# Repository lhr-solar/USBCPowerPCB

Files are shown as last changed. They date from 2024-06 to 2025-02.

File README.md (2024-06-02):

# USBCPowerPCB
Author: Ishan Deshpande

The purpose of this board is to be able to use a USB Type-C laptop charger to run one LV system (such as BPS or Controls). The dongle will act as a breakout; negotiating the power delivery at a fixed voltage with the laptop charger and delivering as much current as needed at a stable voltage of 12V/5V.

Currently under active development. Please reference the [USB-C PD Dongle Design Document](https://cloud.wikis.utexas.edu/wiki/spaces/LHRSOLAR/pages/28287742/2024+-+2026+USB-C+PD+Dongle+Design+Document) for more information.

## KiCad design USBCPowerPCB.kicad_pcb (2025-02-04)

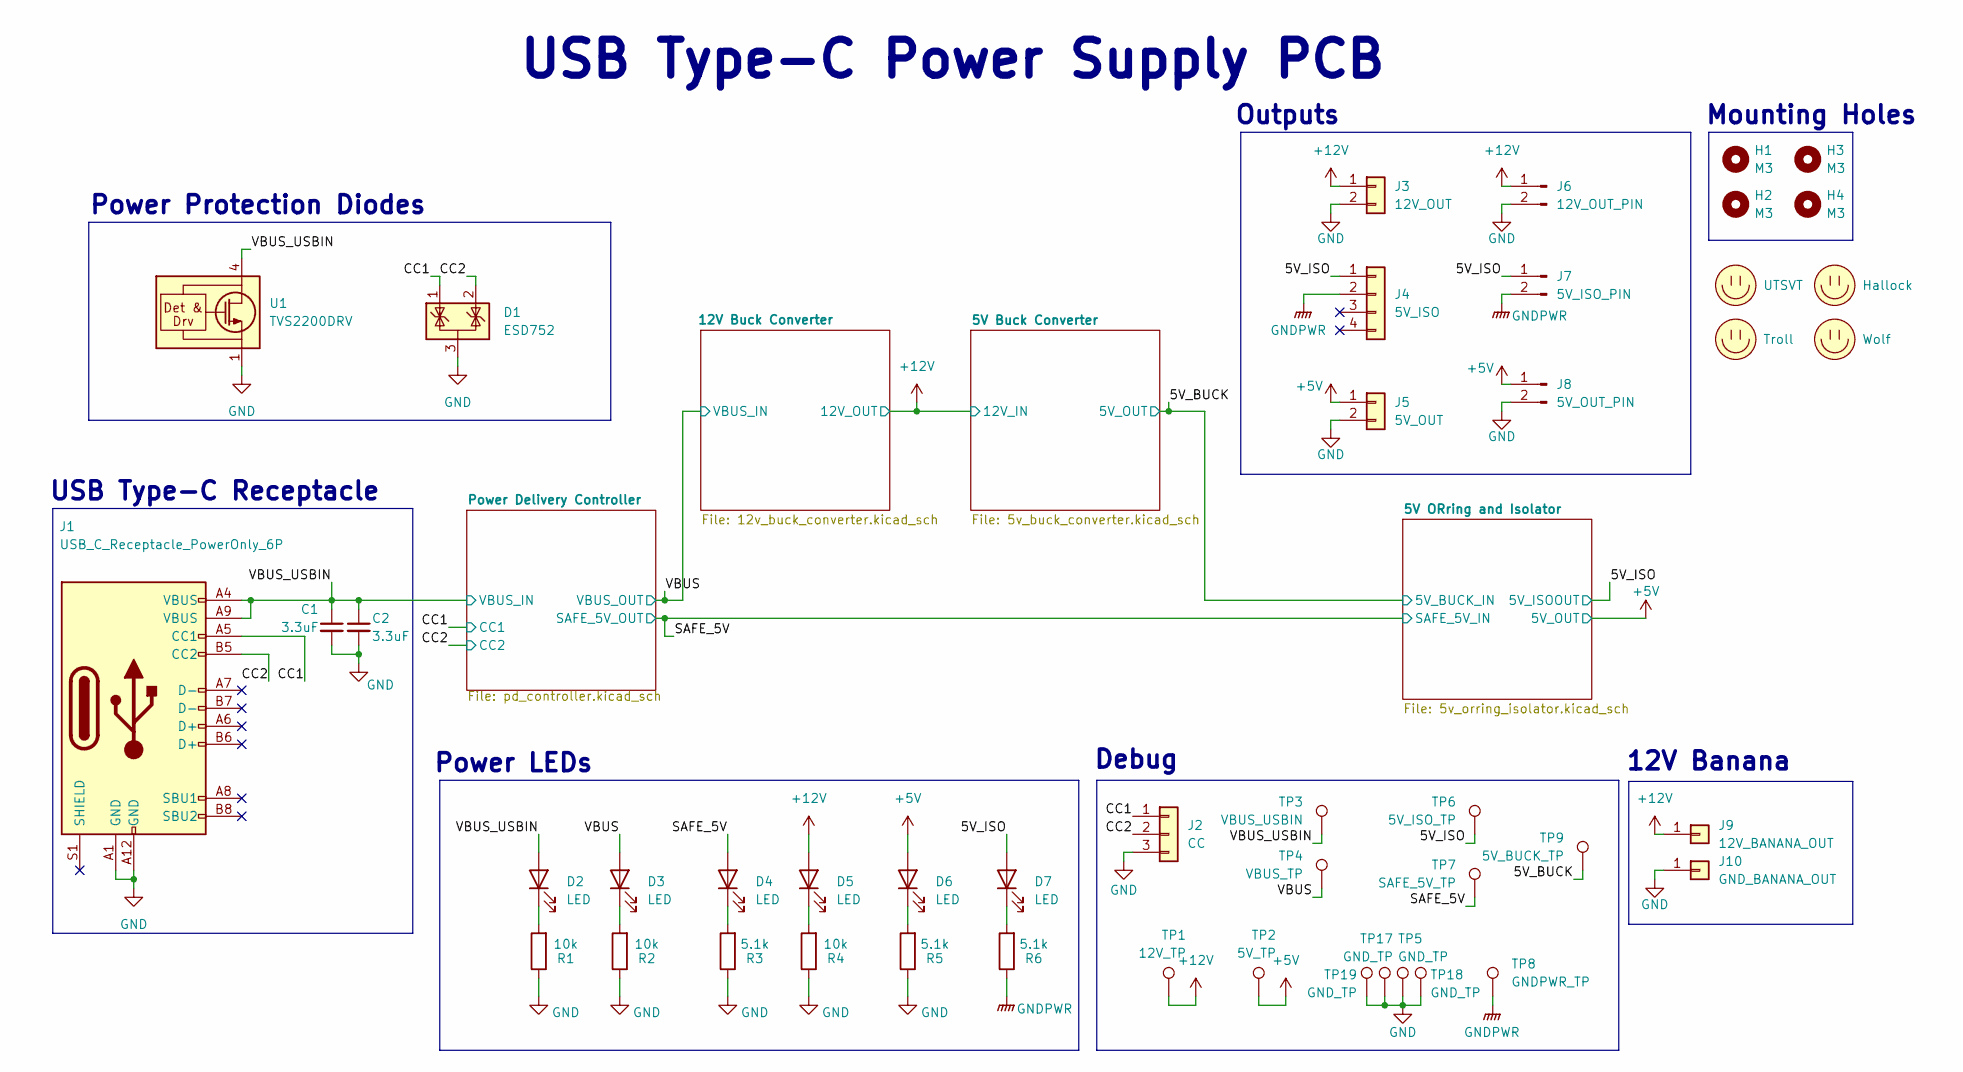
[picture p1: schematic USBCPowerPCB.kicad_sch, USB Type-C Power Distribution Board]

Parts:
C1, C2: 3.3uF; C_0805_2012Metric
D1: ESD752; SOT-23; Mouser Part Number ESD752DBZR
D2, D3, D4, D5, D6, D7: LED; LED_0805_2012Metric
H1, H2, H3, H4: M3; MountingHole_3.2mm_M3
J1: USB_C_Receptacle_PowerOnly_6P; CUI_UJ20-C-H-C-4-SMT-TR
J2: CC; PinHeader_1x03_P2.54mm_Vertical
J3: 12V_OUT; Molex_MicroFit3.0_1x2xP3.00mm_PolarizingPeg_Vertical
J4: 5V_ISO; Molex_MicroFit3.0_1x4xP3.00mm_PolarizingPeg_Vertical
J5: 5V_OUT; Molex_MicroFit3.0_1x2xP3.00mm_PolarizingPeg_Vertical
J6: 12V_OUT_PIN; PinHeader_1x02_P2.54mm_Vertical
J7: 5V_ISO_PIN; PinHeader_1x02_P2.54mm_Vertical
J8: 5V_OUT_PIN; PinHeader_1x02_P2.54mm_Vertical
J9: 12V_BANANA_OUT; Banana_Jack_Horizontal
J10: GND_BANANA_OUT; Banana_Jack_Horizontal
LOGO1: UTSVT; UTSVT_Logo_Symbol
LOGO2: Hallock; Hallock_Image_Tiny
LOGO3: Troll; troll
LOGO4: Wolf; wolf_front
R1, R2, R4: 10k; R_0805_2012Metric
R3, R5, R6: 5.1k; R_0805_2012Metric
TP1: 12V_TP; TestPoint_Plated_Hole_D2.0mm
TP2: 5V_TP; TestPoint_Plated_Hole_D2.0mm
TP3: VBUS_USBIN; TestPoint_Plated_Hole_D2.0mm
TP4: VBUS_TP; TestPoint_Plated_Hole_D2.0mm
TP5, TP17, TP18: GND_TP; TestPoint_THTPad_1.0x1.0mm_Drill0.5mm
TP6: 5V_ISO_TP; TestPoint_Plated_Hole_D2.0mm
TP7: SAFE_5V_TP; TestPoint_Plated_Hole_D2.0mm
TP8: GNDPWR_TP; TestPoint_Plated_Hole_D2.0mm
TP9: 5V_BUCK_TP; TestPoint_Plated_Hole_D2.0mm
TP19: GND_TP; TestPoint_Plated_Hole_D2.0mm
U1: TVS2200DRV; WSON-6-1EP_2x2mm_P0.65mm_EP1x1.6mm

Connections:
+5V: D6.2 (A), J5.1, J8.1, TP2.1; also elsewhere on the board
+12V: D5.2 (A), J3.1, J6.1, J9.1, TP1.1; also elsewhere on the board
/5V_BUCK: TP9.1; also elsewhere on the board
/5V_ISO: D7.2 (A), J4.1, J7.1, TP6.1; also elsewhere on the board
/CC1: D1.1 (K), J1.A5 (CC1), J2.1; also elsewhere on the board
/CC2: D1.2 (K), J1.B5 (CC2), J2.2; also elsewhere on the board
/SAFE_5V: D4.2 (A), TP7.1; also elsewhere on the board
/VBUS: D3.2 (A), TP4.1; also elsewhere on the board
/VBUS_USBIN: C1.1, C2.1, D2.2 (A), J1.A4 (VBUS), J1.A9 (VBUS), J1.B4 (VBUS), J1.B9 (VBUS), TP3.1, U1.4 (IN), U1.5 (IN), U1.6 (IN); also elsewhere on the board
GND: C1.2, C2.2, D1.3 (A), J1.A1 (GND), J1.A12 (GND), J1.B1 (GND), J1.B12 (GND), J2.3, J3.2, J5.2, J6.2, J8.2, J10.1, R1.1, R2.1, R3.1, R4.1, R5.1, TP5.1, TP17.1, TP18.1, TP19.1, U1.1 (GND), U1.2 (GND), U1.3 (GND), U1.7 (GND); also elsewhere on the board
GNDPWR: J4.2, J7.2, R6.1, TP8.1; also elsewhere on the board
unnamed: D2.1 (K), R1.2
unnamed: D3.1 (K), R2.2
unnamed: D4.1 (K), R3.2
unnamed: D5.1 (K), R4.2
unnamed: D6.1 (K), R5.2
unnamed: D7.1 (K), R6.2

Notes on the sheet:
Outputs
Mounting Holes
Debug
Power LEDs
USB Type-C Power Supply PCB
USB Type-C Receptacle
12V Banana
Power Protection Diodes

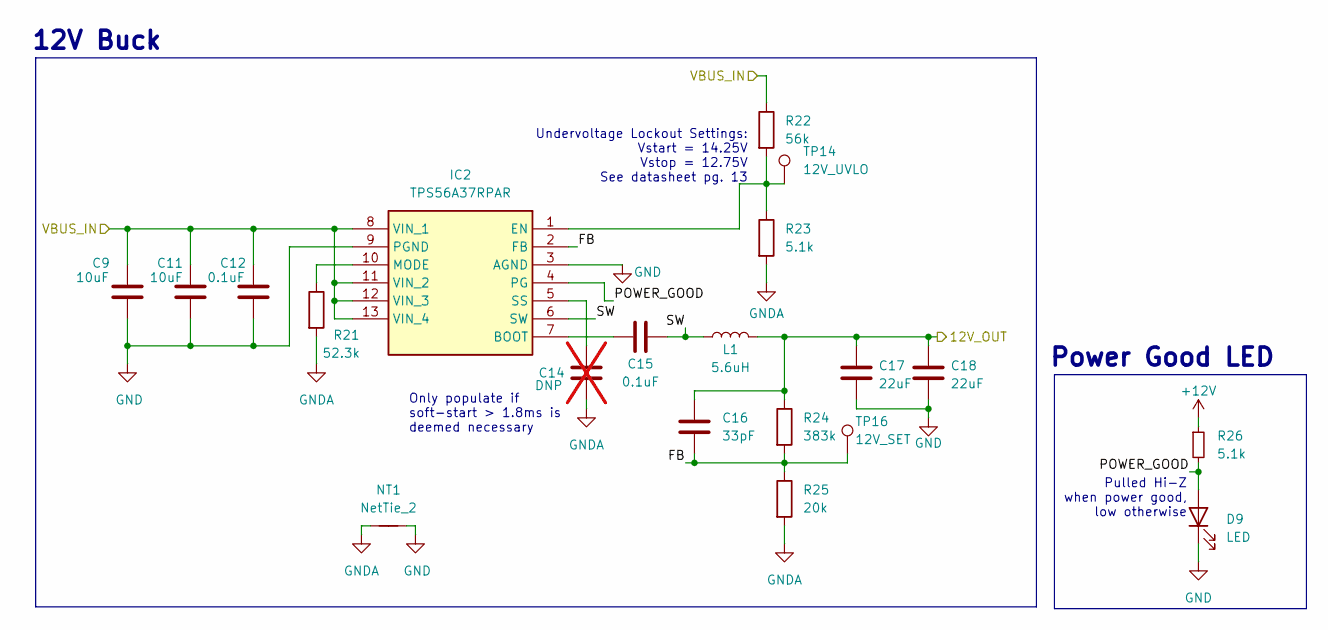
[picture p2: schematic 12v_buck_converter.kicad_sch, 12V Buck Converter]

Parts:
C9, C11: 10uF; C_0805_2012Metric
C12, C15: 0.1uF; C_0805_2012Metric
C14: DNP; C_0805_2012Metric; not fitted
C16: 33pF; C_0805_2012Metric
C17, C18: 22uF; C_0805_2012Metric
D9: LED; LED_0805_2012Metric
IC2: TPS56A37RPAR; Manufacturer_Part_Number TPS56A37RPAR
L1: 5.6uH; L_Bourns_SRP1038C_10.0x10.0mm
NT1: NetTie_2; NetTie-2_SMD_Pad2.0mm
R21: 52.3k; R_0805_2012Metric
R22: 56k; R_0805_2012Metric
R23, R26: 5.1k; R_0805_2012Metric
R24: 383k; R_0805_2012Metric
R25: 20k; R_0805_2012Metric
TP14: 12V_UVLO; TestPoint_THTPad_1.0x1.0mm_Drill0.5mm
TP16: 12V_SET; TestPoint_THTPad_1.0x1.0mm_Drill0.5mm

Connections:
+12V: C16.1, C17.1, C18.1, L1.2, R24.1, R26.1; also elsewhere on the board
/12V Buck Converter/FB: C16.2, IC2.2 (FB), R24.2, R25.1, TP16.1
/12V Buck Converter/POWER_GOOD: D9.2 (A), IC2.4 (PG), R26.2
/12V Buck Converter/SW: C15.2, IC2.6 (SW), L1.1
/VBUS: C9.1, C11.1, C12.1, IC2.8 (VIN_1), IC2.11 (VIN_2), IC2.12 (VIN_3), IC2.13 (VIN_4), R22.1; also elsewhere on the board
GND: C9.2, C11.2, C12.2, C17.2, C18.2, D9.1 (K), IC2.3 (AGND), IC2.9 (PGND), NT1.2; also elsewhere on the board
GNDA: C14.2, NT1.1, R21.2, R23.2, R25.2
unnamed: C15.1, IC2.7 (BOOT)
unnamed: IC2.1 (EN), R22.2, R23.1, TP14.1
unnamed: IC2.10 (MODE), R21.1
unnamed: C14.1, IC2.5 (SS)

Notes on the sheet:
Only populate if soft-start > 1.8ms is deemed necessary
Undervoltage Lockout Settings: Vstart = 14.25V Vstop = 12.75V See datasheet pg. 13
Pulled Hi-Z when power good, low otherwise
Power Good LED
12V Buck

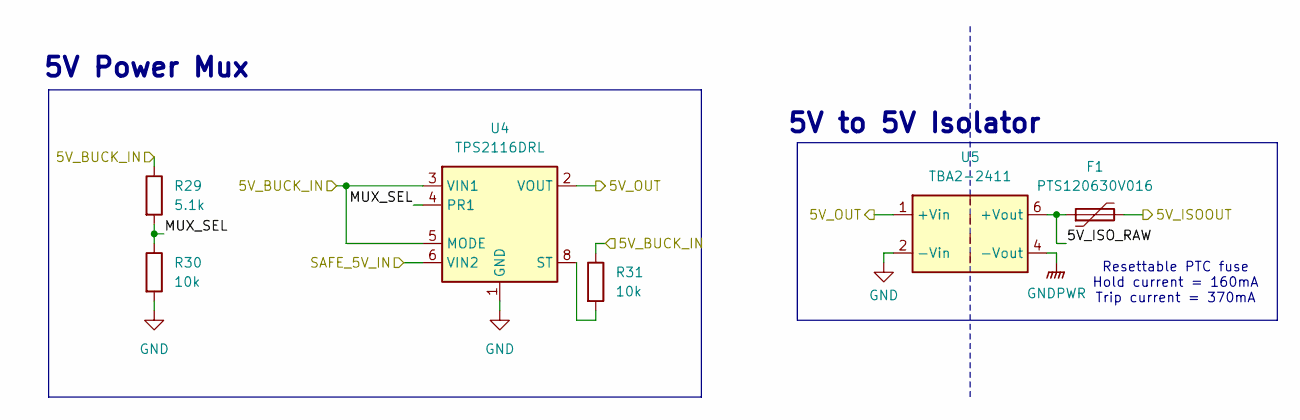
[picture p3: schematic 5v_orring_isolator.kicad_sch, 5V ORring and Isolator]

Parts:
F1: PTS120630V016; Fuse_1206_3216Metric
R29: 5.1k; R_0805_2012Metric
R30, R31: 10k; R_0805_2012Metric
U4: TPS2116DRL; SOT-583-8
U5: TBA2-2411; Converter_DCDC_TRACO_TBA2-xxxx_Single_THT

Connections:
+5V: U4.2 (VOUT), U4.7 (VOUT), U5.1 (+Vin); also elsewhere on the board
/5V ORring and Isolator/5V_ISO_RAW: F1.1, U5.6 (+Vout)
/5V ORring and Isolator/MUX_SEL: R29.2, R30.1, U4.4 (PR1)
/5V_BUCK: R29.1, R31.1, U4.3 (VIN1), U4.5 (MODE); also elsewhere on the board
/5V_ISO: F1.2; also elsewhere on the board
/SAFE_5V: U4.6 (VIN2); also elsewhere on the board
GND: R30.2, U4.1 (GND), U5.2 (-Vin); also elsewhere on the board
GNDPWR: U5.4 (-Vout); also elsewhere on the board
unnamed: R31.2, U4.8 (ST)

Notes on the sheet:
5V Power Mux
Resettable PTC fuse Hold current = 160mA Trip current = 370mA
5V to 5V Isolator

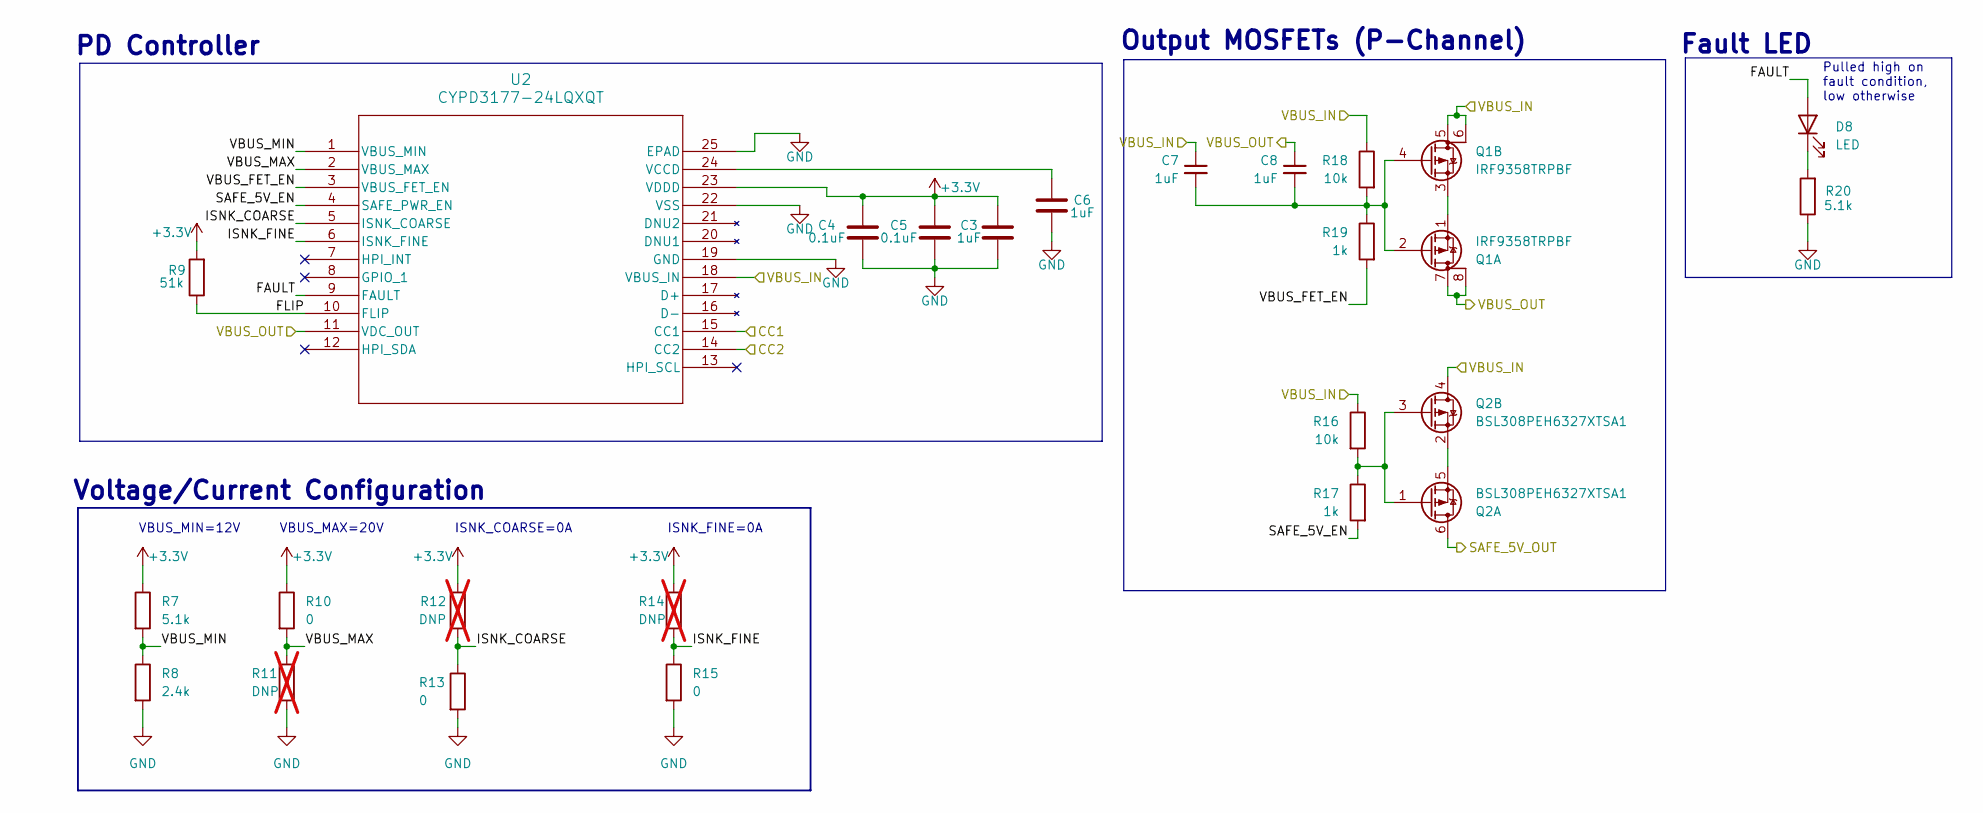
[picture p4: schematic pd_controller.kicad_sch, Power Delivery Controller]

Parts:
C3, C6, C7, C8: 1uF; C_0805_2012Metric
C4, C5: 0.1uF; C_0805_2012Metric
D8: LED; LED_0805_2012Metric
Q1: IRF9358TRPBF; SO-8_3.9x4.9mm_P1.27mm
Q2: BSL308PEH6327XTSA1; SOT-23-6
R7, R20: 5.1k; R_0805_2012Metric
R8: 2.4k; R_0805_2012Metric
R9: 51k; R_0805_2012Metric
R10, R13, R15: 0; R_0805_2012Metric
R11, R12, R14: DNP; R_0805_2012Metric; not fitted
R16, R18: 10k; R_0805_2012Metric
R17, R19: 1k; R_0805_2012Metric
U2: CYPD3177-24LQXQT; CYPD3177-24LQXQT_CYP

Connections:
+3.3V: C3.2, C4.2, C5.2, R7.1, R9.2, R10.1, R12.1, R14.1, U2.23 (VDDD)
/CC1: U2.15 (CC1); also elsewhere on the board
/CC2: U2.14 (CC2); also elsewhere on the board
/Power Delivery Controller/FAULT: D8.2 (A), U2.9 (FAULT)
/Power Delivery Controller/FLIP: R9.1, U2.10 (FLIP)
/Power Delivery Controller/ISNK_COARSE: R12.2, R13.1, U2.5 (ISNK_COARSE)
/Power Delivery Controller/ISNK_FINE: R14.2, R15.1, U2.6 (ISNK_FINE)
/Power Delivery Controller/SAFE_5V_EN: R17.2, U2.4 (SAFE_PWR_EN)
/Power Delivery Controller/VBUS_FET_EN: R19.2, U2.3 (VBUS_FET_EN)
/Power Delivery Controller/VBUS_MAX: R10.2, R11.1, U2.2 (VBUS_MAX)
/Power Delivery Controller/VBUS_MIN: R7.2, R8.1, U2.1 (VBUS_MIN)
/SAFE_5V: Q2.6 (D); also elsewhere on the board
/VBUS: C8.1, Q1.7 (D), Q1.8 (D), U2.11 (VDC_OUT); also elsewhere on the board
/VBUS_USBIN: C7.1, Q1.5 (D), Q1.6 (D), Q2.4 (D), R16.1, R18.1, U2.18 (VBUS_IN); also elsewhere on the board
GND: C3.1, C4.1, C5.1, C6.1, R8.2, R11.2, R13.2, R15.2, R20.1, U2.19 (GND), U2.22 (VSS), U2.25 (EPAD); also elsewhere on the board
unnamed: D8.1 (K), R20.2
unnamed: C7.2, C8.2, Q1.2 (G), Q1.4 (G), R18.2, R19.1
unnamed: Q1.1 (S), Q1.3 (S)
unnamed: Q2.1 (G), Q2.3 (G), R16.2, R17.1
unnamed: Q2.2 (S), Q2.5 (S)
unnamed: C6.2, U2.24 (VCCD)

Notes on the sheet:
VBUS_MAX=20V
Fault LED
Voltage/Current Configuration
Pulled high on fault condition, low otherwise
PD Controller
ISNK_COARSE=0A
Output MOSFETs (P-Channel)
ISNK_FINE=0A
VBUS_MIN=12V

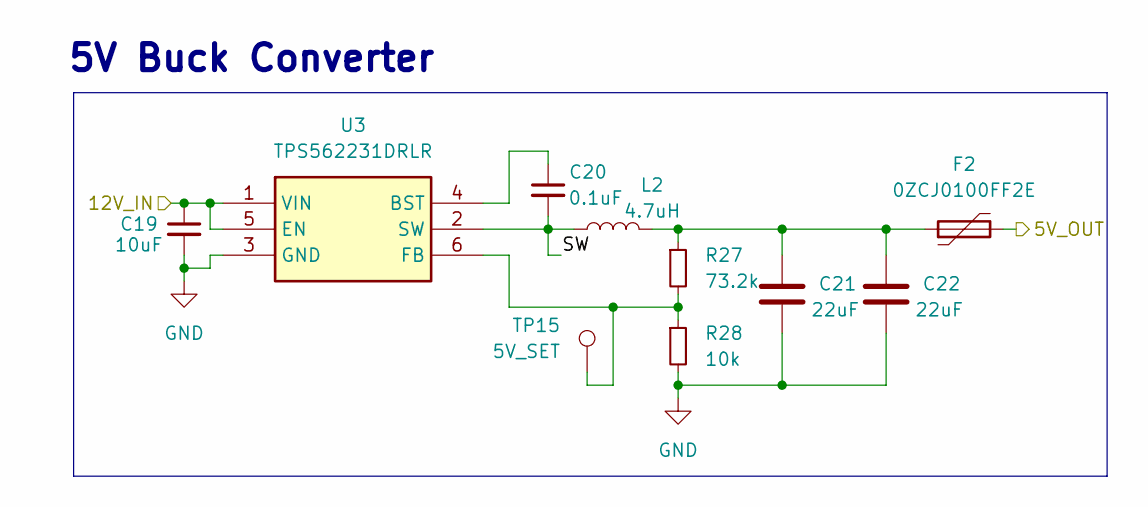
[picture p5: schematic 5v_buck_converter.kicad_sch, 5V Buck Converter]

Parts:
C19: 10uF; C_0805_2012Metric
C20: 0.1uF; C_0805_2012Metric
C21, C22: 22uF; C_0805_2012Metric
F2: 0ZCJ0100FF2E; Fuse_1206_3216Metric
L2: 4.7uH; INDPM5452X300N
R27: 73.2k; R_0805_2012Metric
R28: 10k; R_0805_2012Metric
TP15: 5V_SET; TestPoint_THTPad_1.0x1.0mm_Drill0.5mm
U3: TPS562231DRLR; SOT-563

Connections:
+12V: C19.1, U3.1 (VIN), U3.5 (EN); also elsewhere on the board
/5V Buck Converter/SW: C20.2, L2.1, U3.2 (SW)
/5V_BUCK: F2.2; also elsewhere on the board
GND: C19.2, C21.2, C22.2, R28.2, U3.3 (GND); also elsewhere on the board
unnamed: C21.1, C22.1, F2.1, L2.2, R27.1
unnamed: C20.1, U3.4 (BST)
unnamed: R27.2, R28.1, TP15.1, U3.6 (FB)

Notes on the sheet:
5V Buck Converter

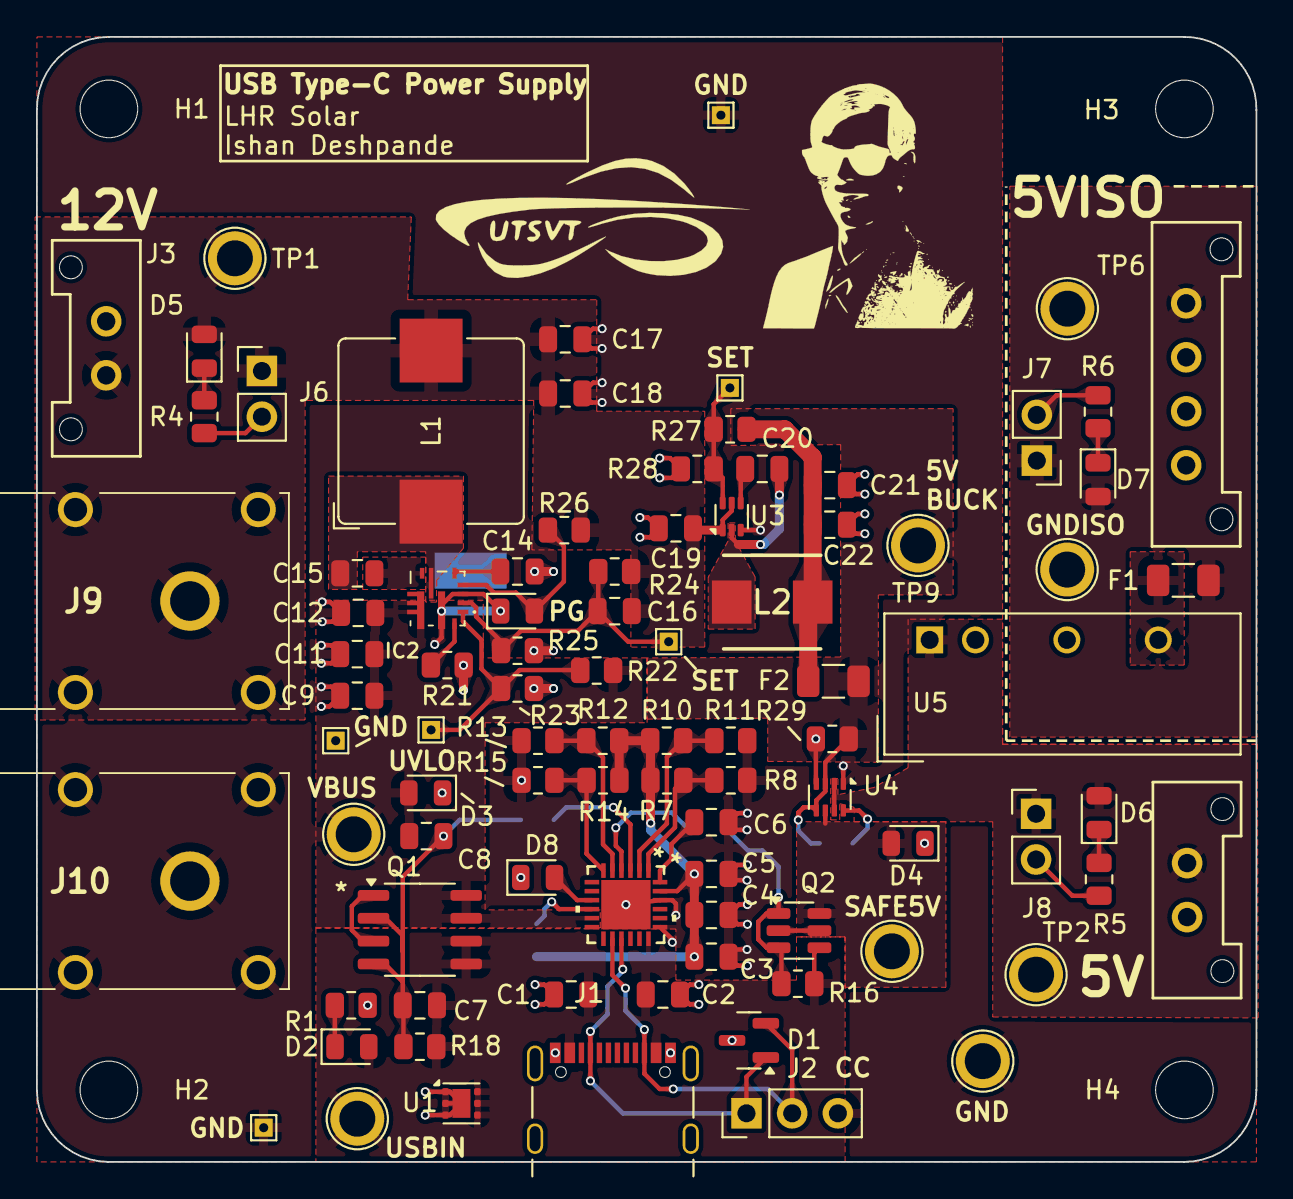
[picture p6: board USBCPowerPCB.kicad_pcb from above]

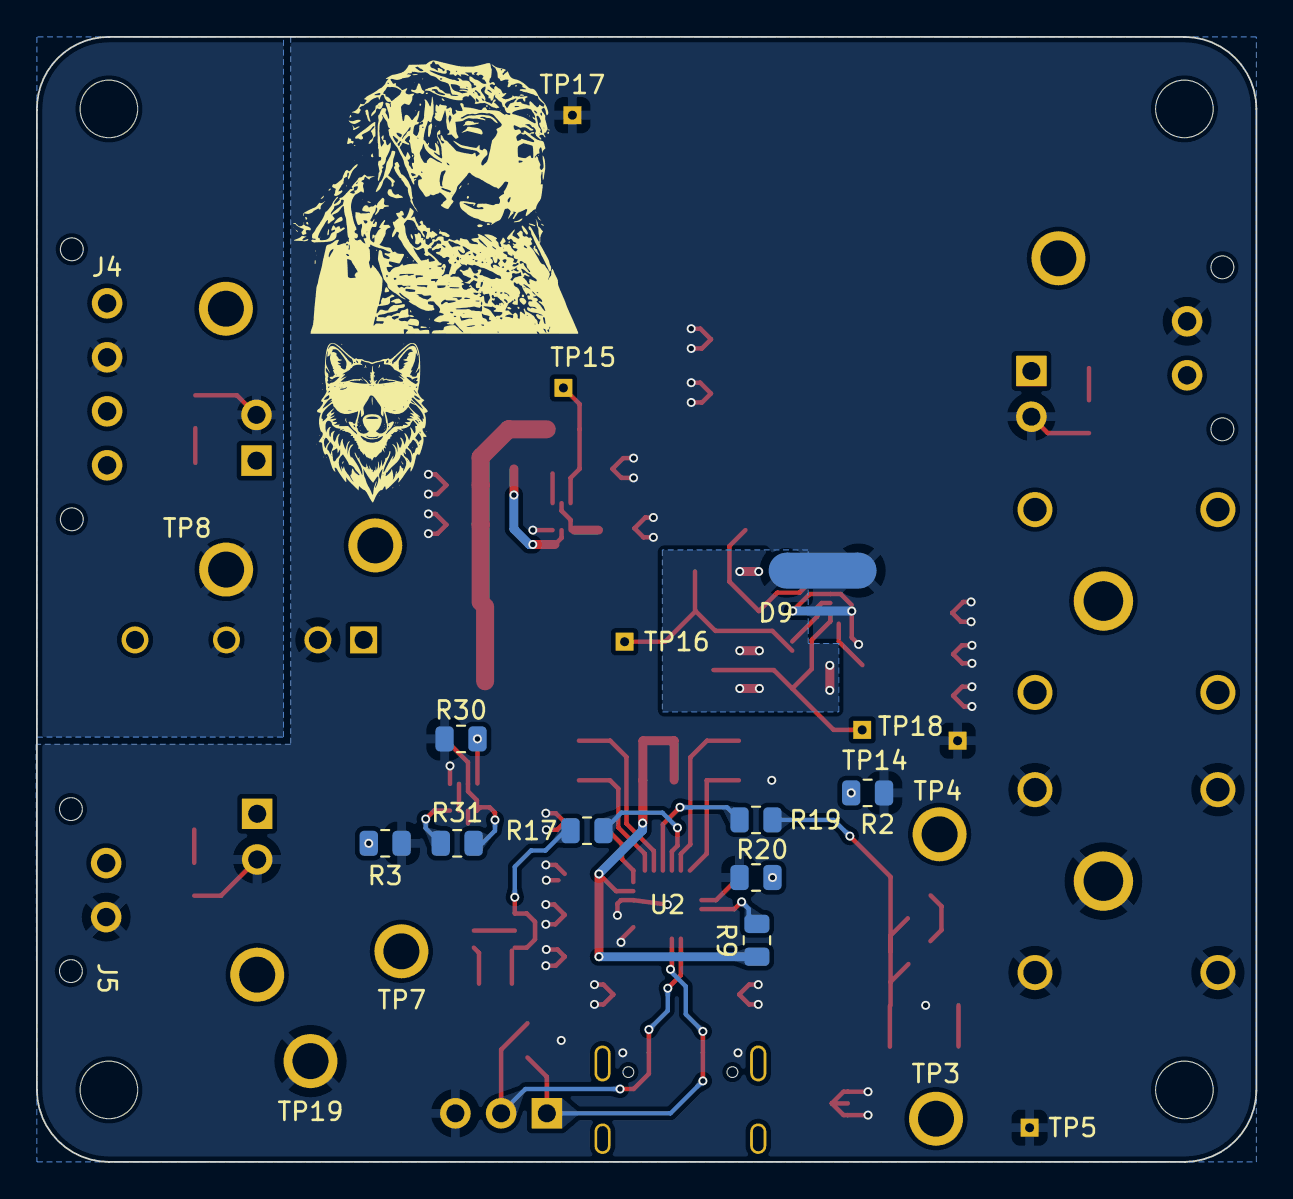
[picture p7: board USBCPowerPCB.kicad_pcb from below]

Board: 2 copper layers, 67.8 x 62.5 mm, 106 parts (11 on the bottom side), 47 nets.

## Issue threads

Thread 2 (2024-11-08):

Change footprint for 12V Buck

IshDeshpa, 2024-11-08:
Footprint has all pads completely under the chip. Change to something you can actually solder. Should be same pad placement and dimensions but just longer pads.

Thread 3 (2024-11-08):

Remove 5V Iso

IshDeshpa, 2024-11-08:
No longer necessary since we're either doing no isolation at all or onboard isolation (for CAN)

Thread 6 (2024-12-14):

Shorten VBUS power plane slightly so that GND can connect

IshDeshpa, 2024-12-14:
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

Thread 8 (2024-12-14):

Change to 50k

IshDeshpa, 2024-12-14:
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
[Datasheet](https://www.mouser.com/datasheet/2/196/Infineon_EZ_PD_BCR_Datasheet_USB_Type_C_Port_Contr-3361317.pdf) specifies 50k for non-data-capable operation

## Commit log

2024-05-21 rename, add submodule
    [USBCPowerPCB.kicad_pcb, USBCPowerPCB.kicad_sch]
2024-06-02 first draft of USBC controller and 12V buck converter schematics
    [12v_buck_converter.kicad_sch, 5v_buck_converter.kicad_sch, USBCPowerPCB.kicad_sch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]
2024-06-23 Finished 5V buck converter schematic
    [12v_buck_converter.kicad_sch, 5v_buck_converter.kicad_sch, USBCPowerPCB.kicad_sch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]
2024-06-23 added power good LED indicators
    [12v_buck_converter.kicad_sch, 5v_buck_converter.kicad_sch, pd_controller.kicad_sch]
2024-06-23 change current protection to current monitoring
    [USBCPowerPCB.kicad_sch, current_monitoring.kicad_sch]
2024-07-27 moving laptops
    [Current Sense Selection.xlsx, current_monitoring.kicad_sch]
2024-08-14 initial draft w/ current sense for 5V
    [12v_buck_converter.kicad_sch, 5v_buck_converter.kicad_sch, Current Sense Selection.xlsx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]
2024-08-14 accidentally flipped current sense; also routed high level schematic
    [12v_buck_converter.kicad_sch, USBCPowerPCB.kicad_sch, current_monitoring.kicad_sch]
2024-08-14 finished first draft
    [USBCPowerPCB.kicad_sch, current_monitoring.kicad_sch]
2024-08-14 changed to 1-channel chip for current sense & fixed ERC
    [USBCPowerPCB.kicad_sch, current_monitoring.kicad_sch, pd_controller.kicad_sch]
2024-08-14 added proper current limiting resistors for 2mA on seven seg
    [current_monitoring.kicad_sch]
2024-08-15 updated with some new footprints (have yet to finish footprint assignment; also need to switch out inductor for 5V buck)
    [12v_buck_converter.kicad_sch, 5v_buck_converter.kicad_sch, USBCPowerPCB.kicad_pcb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]
2024-08-29 add calcs for TPS56A37
    [TPS56A37.xlsx]
2024-08-30 changed 5v buck to TPS56A37
    [12v_buck_converter.kicad_sch, 5v_buck_converter.kicad_sch, USBCPowerPCB.kicad_sch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]
2024-08-31 changed buck calcs for 5v buck
    [BuckCalcs.xlsx, TPS56A37.xlsx]
2024-08-31 almost done w/ schematic, just need to finish footprint assignment (make sure buck converter components are correctly chosen and there aren't caps that need to be different and stuff)
    [12v_buck_converter.kicad_sch, 5v_buck_converter.kicad_sch, 5v_orring_diode_isolator.kicad_sch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]
2024-08-31 cleaned up schematic, added power LEDs and testpoints
    [12v_buck_converter.kicad_sch, 5v_buck_converter.kicad_sch, 5v_orring_diode_isolator.kicad_sch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]
2024-09-01 finished footprint assignment
    [12v_buck_converter.kicad_sch, 5v_buck_converter.kicad_sch, 5v_orring_diode_isolator.kicad_sch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]
2024-09-01 added protection diodes
    [USBCPowerPCB.kicad_sch]
2024-09-02 changed resistor values on infineon chip output mosfets to match EZ PD BCR datasheet better
    [pd_controller.kicad_sch]
2024-09-02 removed parallel resistors
    [12v_buck_converter.kicad_sch]
2024-09-07 address review changes, add more output protections
    [12v_buck_converter.kicad_sch, 5v_buck_converter.kicad_sch, 5v_orring_diode_isolator.kicad_sch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]
2024-09-07 footprint assignment again
    [12v_buck_converter.kicad_sch, 5v_buck_converter.kicad_sch, 5v_orring_isolator.kicad_sch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]
2024-09-14 finished addressing review comments & organized bom with p/ns for everything
    [12v_buck_converter.kicad_sch, 5v_buck_converter.kicad_sch, 5v_orring_isolator.kicad_sch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]
2024-09-14 added banana jacks for input/output to 12v buck, for isolated 12v buck testing. also filled in more part numbers for connectors.
    [12v_buck_converter.kicad_sch, 5v_buck_converter.kicad_sch, 5v_orring_isolator.kicad_sch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]
2024-09-15 intermediate progress push before addressing Champers' and Lakshay's review comments
    [12v_buck_converter.kicad_sch, 5v_buck_converter.kicad_sch, 5v_orring_isolator.kicad_sch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]
2024-09-16 Addressed most of the review comments, fixed power protection, added bigger caps & better part selection on 12V and 5V out, changed 5V buck inductor, fixed power good & fault LEDs
    [12v_buck_converter.kicad_sch, 5v_buck_converter.kicad_sch, 5v_orring_isolator.kicad_sch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]
2024-09-16 Added ideal diode controller & mosfet for 12V buck power protection
    [12v_buck_converter.kicad_sch, 5v_buck_converter.kicad_sch, 5v_orring_isolator.kicad_sch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]
2024-09-16 removed 12v output protection since buck already has OV
    [12v_buck_converter.kicad_sch, USBCPowerPCB.kicad_pcb]
2024-09-18 started routing
    [12v_buck_converter.kicad_sch, 5v_buck_converter.kicad_sch, USBCPowerPCB.kicad_pcb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]
2024-09-18 more layout updates
    [USBCPowerPCB.kicad_pcb]
2024-09-19 added step files
    [43650-0215.stp, 73099-0.stp, 73099-2.stp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]
2024-09-23 redid cypd layout, halfway through 12v buck layout
    [12v_buck_converter.kicad_sch, 5v_buck_converter.kicad_sch, 5v_orring_isolator.kicad_sch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]
2024-09-23 big component layout moment
    [12v_buck_converter.kicad_sch, 5v_buck_converter.kicad_sch, USBCPowerPCB.kicad_pcb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]
2024-09-23 added testpoints everywhere :)
    [USBCPowerPCB.kicad_pcb, USBCPowerPCB.kicad_sch]
2024-09-23 buck calcs save
    [BuckCalcs.xlsx]
2024-09-23 cleared most DRC errors, need to fix DRC warnings
    [USBCPowerPCB.kicad_pcb, USBCPowerPCB.kicad_sch]
2024-09-26 DRC passing: no warnings, no errors, no problem ✊🏿
    [USBCPowerPCB.kicad_pcb]
2024-10-02 made some changes to address review comments, still need to fix DRC fully and add UTSVT & Hallock silkscreen
    [USBCPowerPCB.kicad_pcb, USBCPowerPCB.kicad_sch]
2024-10-04 fixed clearance violations and made board 3mm shorter
    [5v_orring_isolator.kicad_sch, USBCPowerPCB.kicad_pcb]
2024-10-05 cleaning up stuff
    [USBCPowerPCB.kicad_pcb]
2024-10-05 critical updates
    [USBCPowerPCB.kicad_pcb]
2024-10-08 addressed some review comments from my 🐐 champers fu
    [12v_buck_converter.kicad_sch, 5v_buck_converter.kicad_sch, USBCPowerPCB.kicad_pcb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]
2024-10-09 ready for review 👍🏾
    [USBCPowerPCB.kicad_pcb, pd_controller.kicad_sch]
2024-10-13 uncurse the cursed board
    [USBCPowerPCB.kicad_pcb]
2024-10-13 addressed most of the review shit except the TVS/overcurrent protection on the 5V output
    [USBCPowerPCB.kicad_pcb]
2024-10-14 added fuse to protect 5V buck converter output
    [5v_buck_converter.kicad_sch, USBCPowerPCB.kicad_pcb]
2024-10-15 i am jesus christ in the flesh.
    [12v_buck_converter.kicad_sch, 5v_buck_converter.kicad_sch, 5v_orring_isolator.kicad_sch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]
2024-10-15 i am not jesus christ...
    [USBCPowerPCB-B_Cu.gbl, USBCPowerPCB-B_Mask.gbs, USBCPowerPCB-B_Paste.gbp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]
